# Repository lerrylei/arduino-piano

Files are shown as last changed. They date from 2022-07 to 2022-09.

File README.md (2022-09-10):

# mechKeyPiano
A mechanical keyboard... but the OTHER type of "keyboard."



## About

This DIY 3D printed monophonic (1 key at a time) keyboard uses 12 mechanical keyboard switches for piano keys. It is powered by an Arduino UNO and fitted with a speaker and a potentiometer to change between 3 octaves. Watch the video demo below to see how it sounds!

<a href="https://youtu.be/XHjSW5ESeuM">
  
</a>

## Design
3D overview of the keyboard case. I printed using a .4mm nozzle and 20% infill. Supports are necessary for some parts but do not put too many. Printing took around 2 days to fully complete all parts but can be reduced signifcantly by reducing infill and lowering the thickness of the walls. Since the STL files were larger than my print area, I had to split the case into [multiple parts](CAD%20Files/Split%20CAD).



## Assembly
First, gather all necessary parts before building. This includes the 3D printed case, keys and screws, 12 mechanical keyboard switches, 1 potentiometer, 1 speaker/piezo, a mini breadboard, and an Arduino Uno. Components are placed as shown in the second image. 
<details>
  <summary><b>Components Layout</b></summary>
  
  
</details>

Next, wire up the mechanical switches to the mini breadboard according to the circuit diagram in the next sections. Be sure to route the wire under and through the keycap holder prior to soldering. 
<details>
  <summary><b>Wiring Switches</b></summary>
  
</details>

Then, attach the piezo speaker and the potentiometer attached to the top of the case. 
<details>
  <summary><b>Potentiometer/Speaker</b></summary>
  
</details>

Lastly, screw in piano keys on top of the mechanical switches and cover the top case.
<details>
  <summary><b>Keys</b></summary>
   
</details>

Done!



## Circuit Diagram
Refer to the following [circuit diagram](Assets/Circuit%20Diagram.png) for information on how to wire components together.

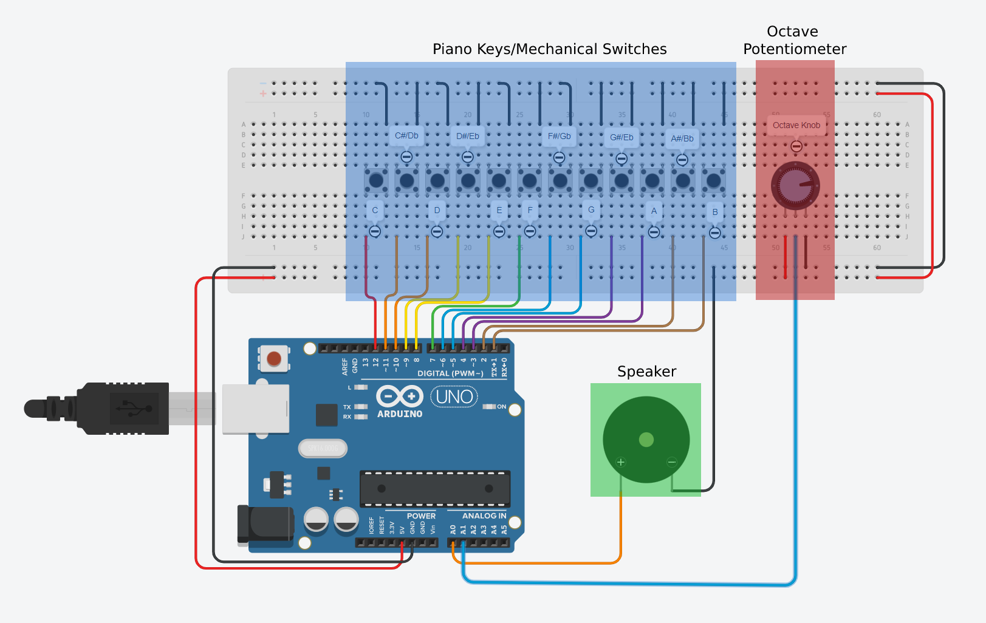
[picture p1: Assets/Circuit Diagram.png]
Circuit Diagram


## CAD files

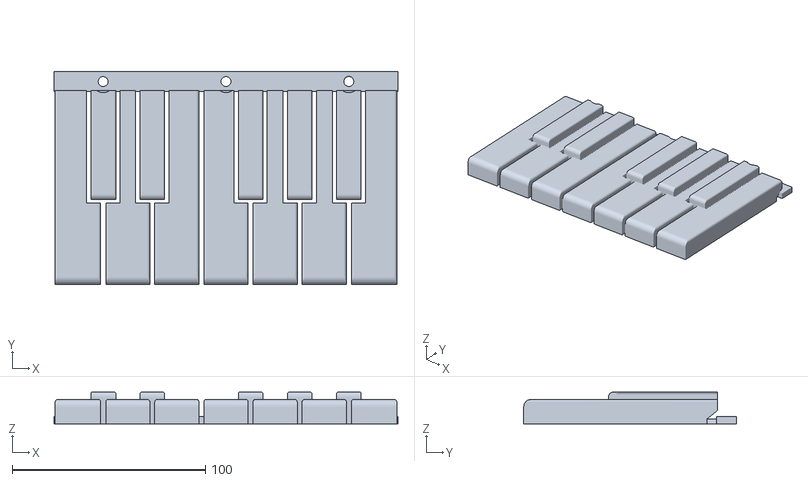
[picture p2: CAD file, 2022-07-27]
CAD Files/Keys.stl
177.8 x 109.9 x 16.5

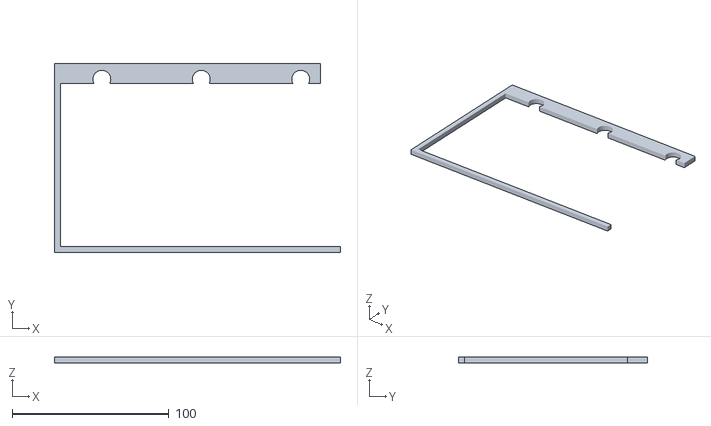
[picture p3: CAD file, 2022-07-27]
CAD Files/Split CAD/Top Case L.stl
182.6 x 120.4 x 3.81

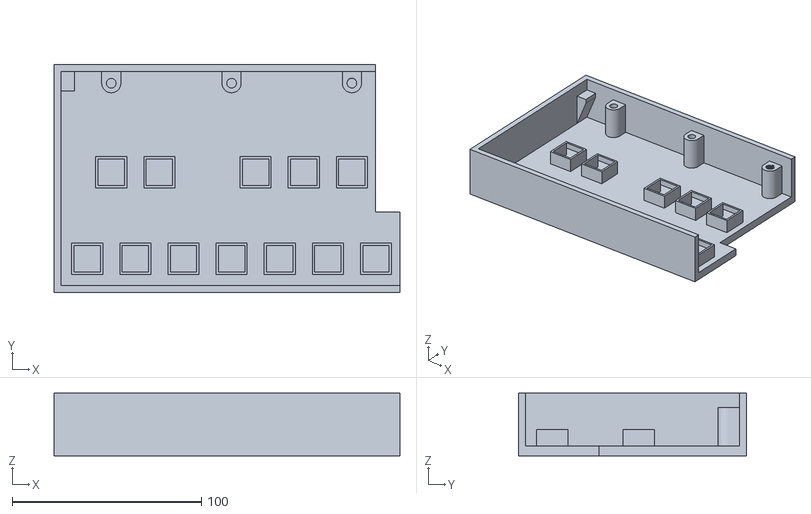
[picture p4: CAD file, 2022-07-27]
CAD Files/Split CAD/Bottom Case L.stl
182.6 x 120.4 x 33.0

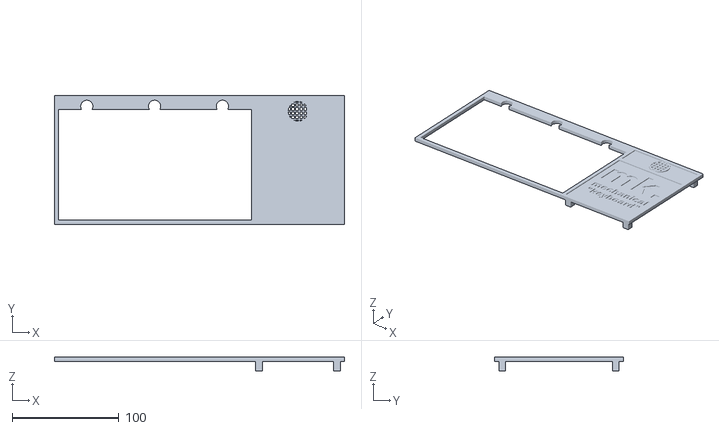
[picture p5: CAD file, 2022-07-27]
CAD Files/Top Case.stl
271.5 x 120.4 x 12.7

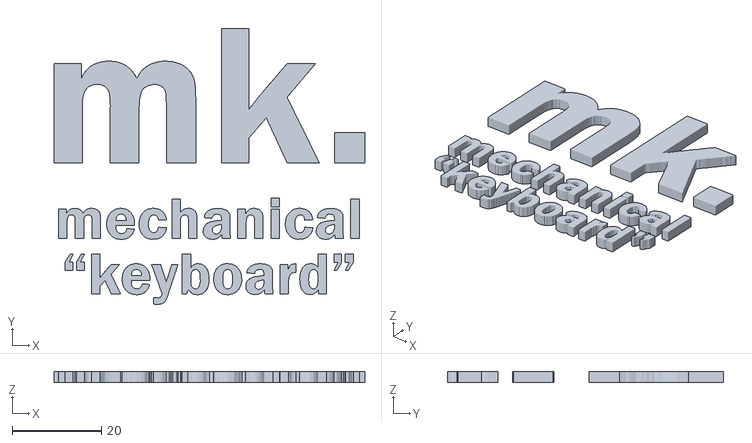
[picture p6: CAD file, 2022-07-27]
CAD Files/Logo.stl
69.7 x 61.8 x 2.54

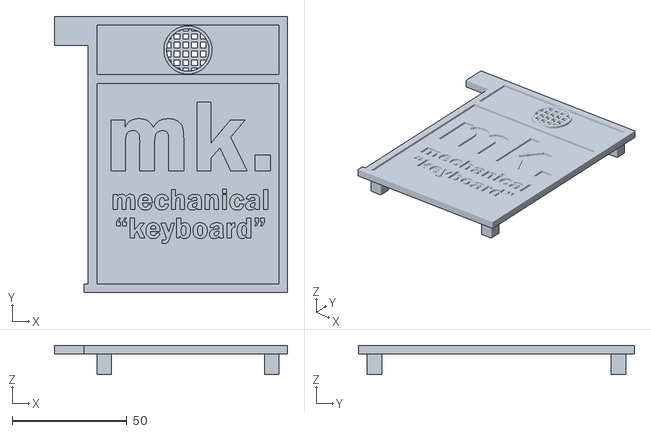
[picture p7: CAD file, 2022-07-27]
CAD Files/Split CAD/Top Case R.stl
101.7 x 120.4 x 12.7

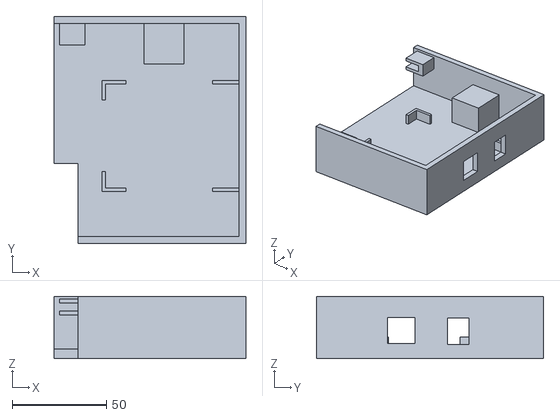
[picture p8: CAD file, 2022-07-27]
CAD Files/Split CAD/Bottom Case R.stl
101.7 x 120.4 x 33.0

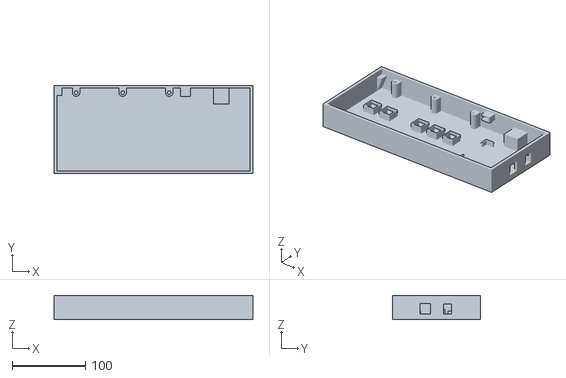
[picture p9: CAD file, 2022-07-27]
CAD Files/Bottom Case.stl
271.5 x 120.4 x 33.0

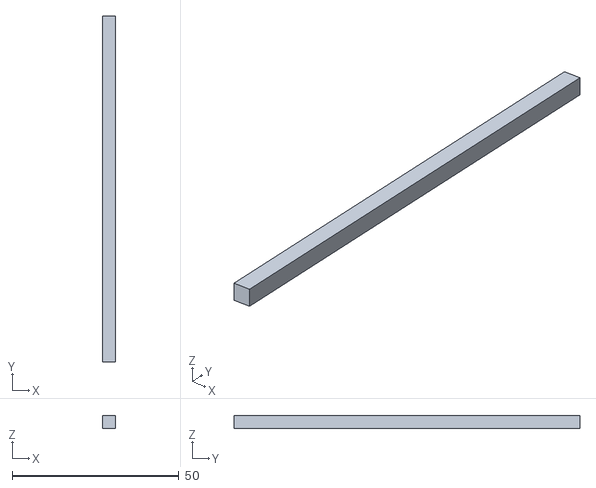
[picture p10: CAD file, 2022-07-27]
CAD Files/Split CAD/Addon.stl
3.81 x 103.9 x 3.81

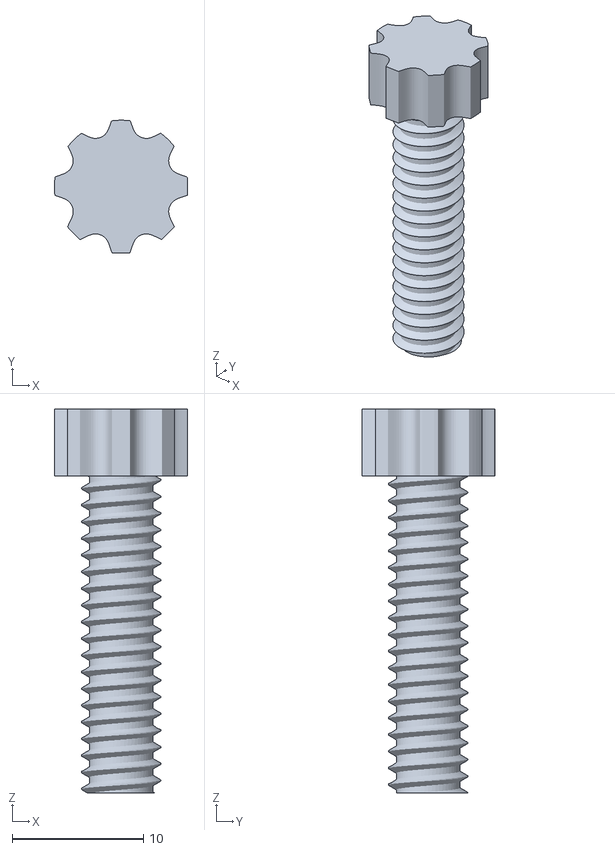
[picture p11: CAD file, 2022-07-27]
CAD Files/Screw.stl
10.1 x 10.1 x 29.2

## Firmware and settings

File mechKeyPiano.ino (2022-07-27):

//define speaker pin
const int speaker = A0;

//define octave potentiometer pin
const int octaveKnob = A1;

//piano key pins array
const uint8_t keys[] = {12, 11, 10, 9, 8, 7, 6, 5, 4, 3, 2, 1};

//three octaves of notes array
const int notes[] = {
//C,  C#,    D,   D#,   E,   F,   F#,   G,   G#,   A,   A#,   B
 131, 139, 147, 156, 165, 175, 185, 196, 208, 220, 233, 247, // Octave 3
};

//count the number of keys
int numKeys = sizeof(keys);

void setup(){
  //attach keys as inputs
  for (uint8_t i = 0; i < numKeys; i++) {
    pinMode(keys[i], INPUT_PULLUP); //Pull up - mechanical switch only has 2 prongs
  }
  //speaker as output
  pinMode(A0, OUTPUT);
  
  //octave knob as input
  pinMode(A1, INPUT);
}

void loop(){
  int octaveKnobRaw = analogRead(octaveKnob); //read raw output of octave knob
  int octaveMap = map(octaveKnobRaw, 800, 200, 0, 2); //convert raw output to 0 to 2 multiplier scale
  
  int freq = 0; //piano frequency variable
  
  //check state of each key, if a key pressed then change freq to the equivalent tone
  for (uint8_t i=0; i < numKeys; i++) {
    if (digitalRead(keys[i]) == LOW) {
      freq = notes[i]*pow(2,octaveMap); //octaveMap multiplier, every 2x = higher octave
    }
  }
  
  if (freq) { //if freq is anything other than 0, play tone
    tone(speaker, freq);
  }
  else {
    noTone(speaker);
  }
}

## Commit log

2022-07-27 Added CAD Files
    [Addon.stl, Bottom Case L.stl, Bottom Case R.stl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]
2022-09-10 Added assembly instructions
